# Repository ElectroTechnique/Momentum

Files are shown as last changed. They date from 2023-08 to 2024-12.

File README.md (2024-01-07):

# Momentum
Electrotechnique Momentum Synthesizer

3D Models - STL models of 3D printed components

Manual - User Manual including build guide

Momentum - Folder with source code, set-up for PlatformIO

SDCard - Folder with 'factory presets'. Copy the contents of the SDCard folder straight onto a formatted micro SD card

# Flashing firmware
Get the firmware hex file from [RELEASES](https://github.com/ElectroTechnique/Momentum/releases) on the right
See the User Manual sections on Flashing Firmware - use either TyUploader (recommended) or Teensy Loader.
TyUploader is in [TyTools Releases](https://github.com/Koromix/tytools/releases)
Teensy Loader is at [PJRC](https://www.pjrc.com/teensy/loader.html)

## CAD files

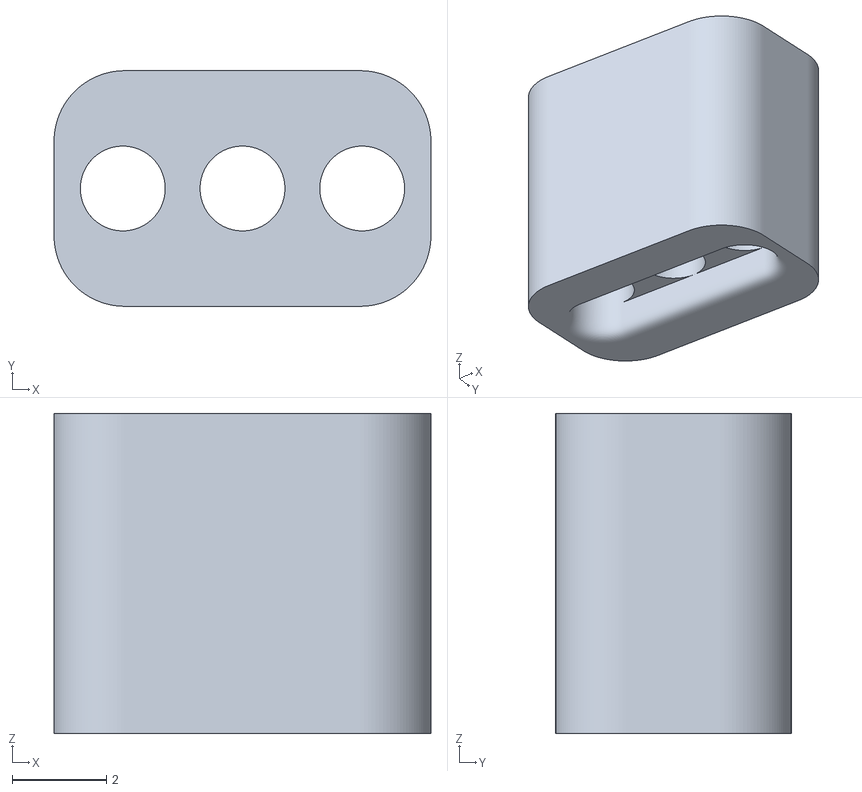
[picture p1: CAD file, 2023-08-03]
3D Models/3mm Bicolour LED Standoff.stl
8.00 x 5.00 x 6.80

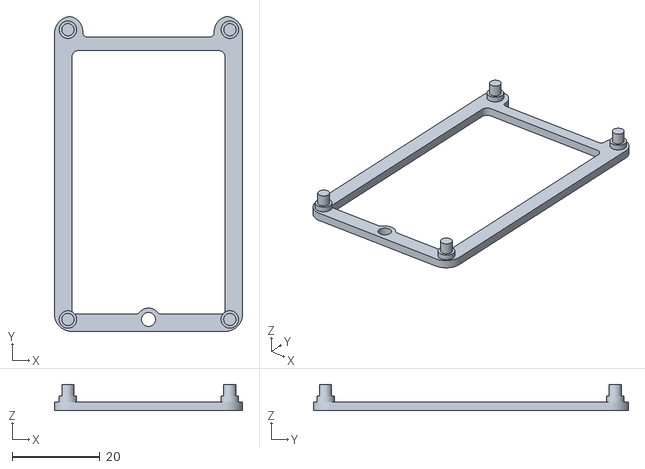
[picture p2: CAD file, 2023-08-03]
3D Models/240x320 TFT Standoff.stl
43.0 x 72.0 x 6.00

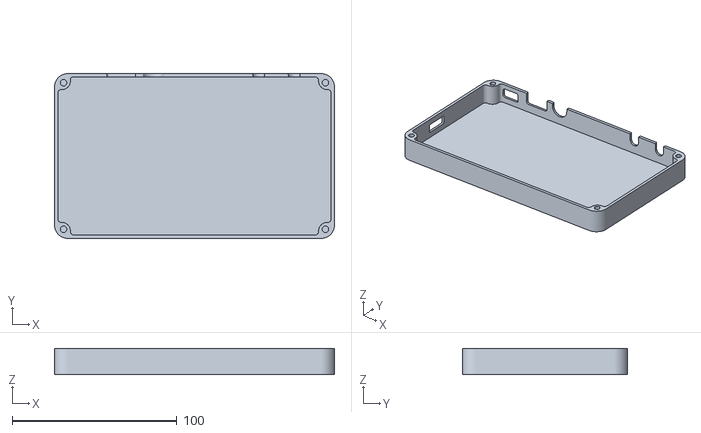
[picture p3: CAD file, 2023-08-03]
3D Models/Momentum Case USB C Brass Inserts.stl
170.0 x 100.0 x 16.0

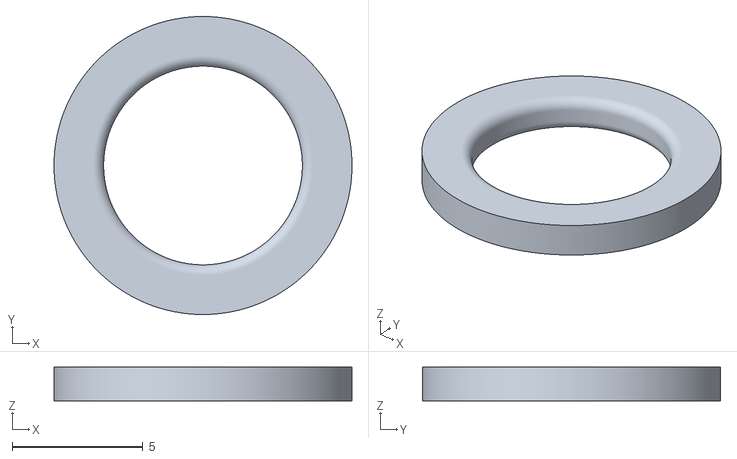
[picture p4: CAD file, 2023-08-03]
3D Models/Encoder Spacer.stl
11.4 x 11.4 x 1.30

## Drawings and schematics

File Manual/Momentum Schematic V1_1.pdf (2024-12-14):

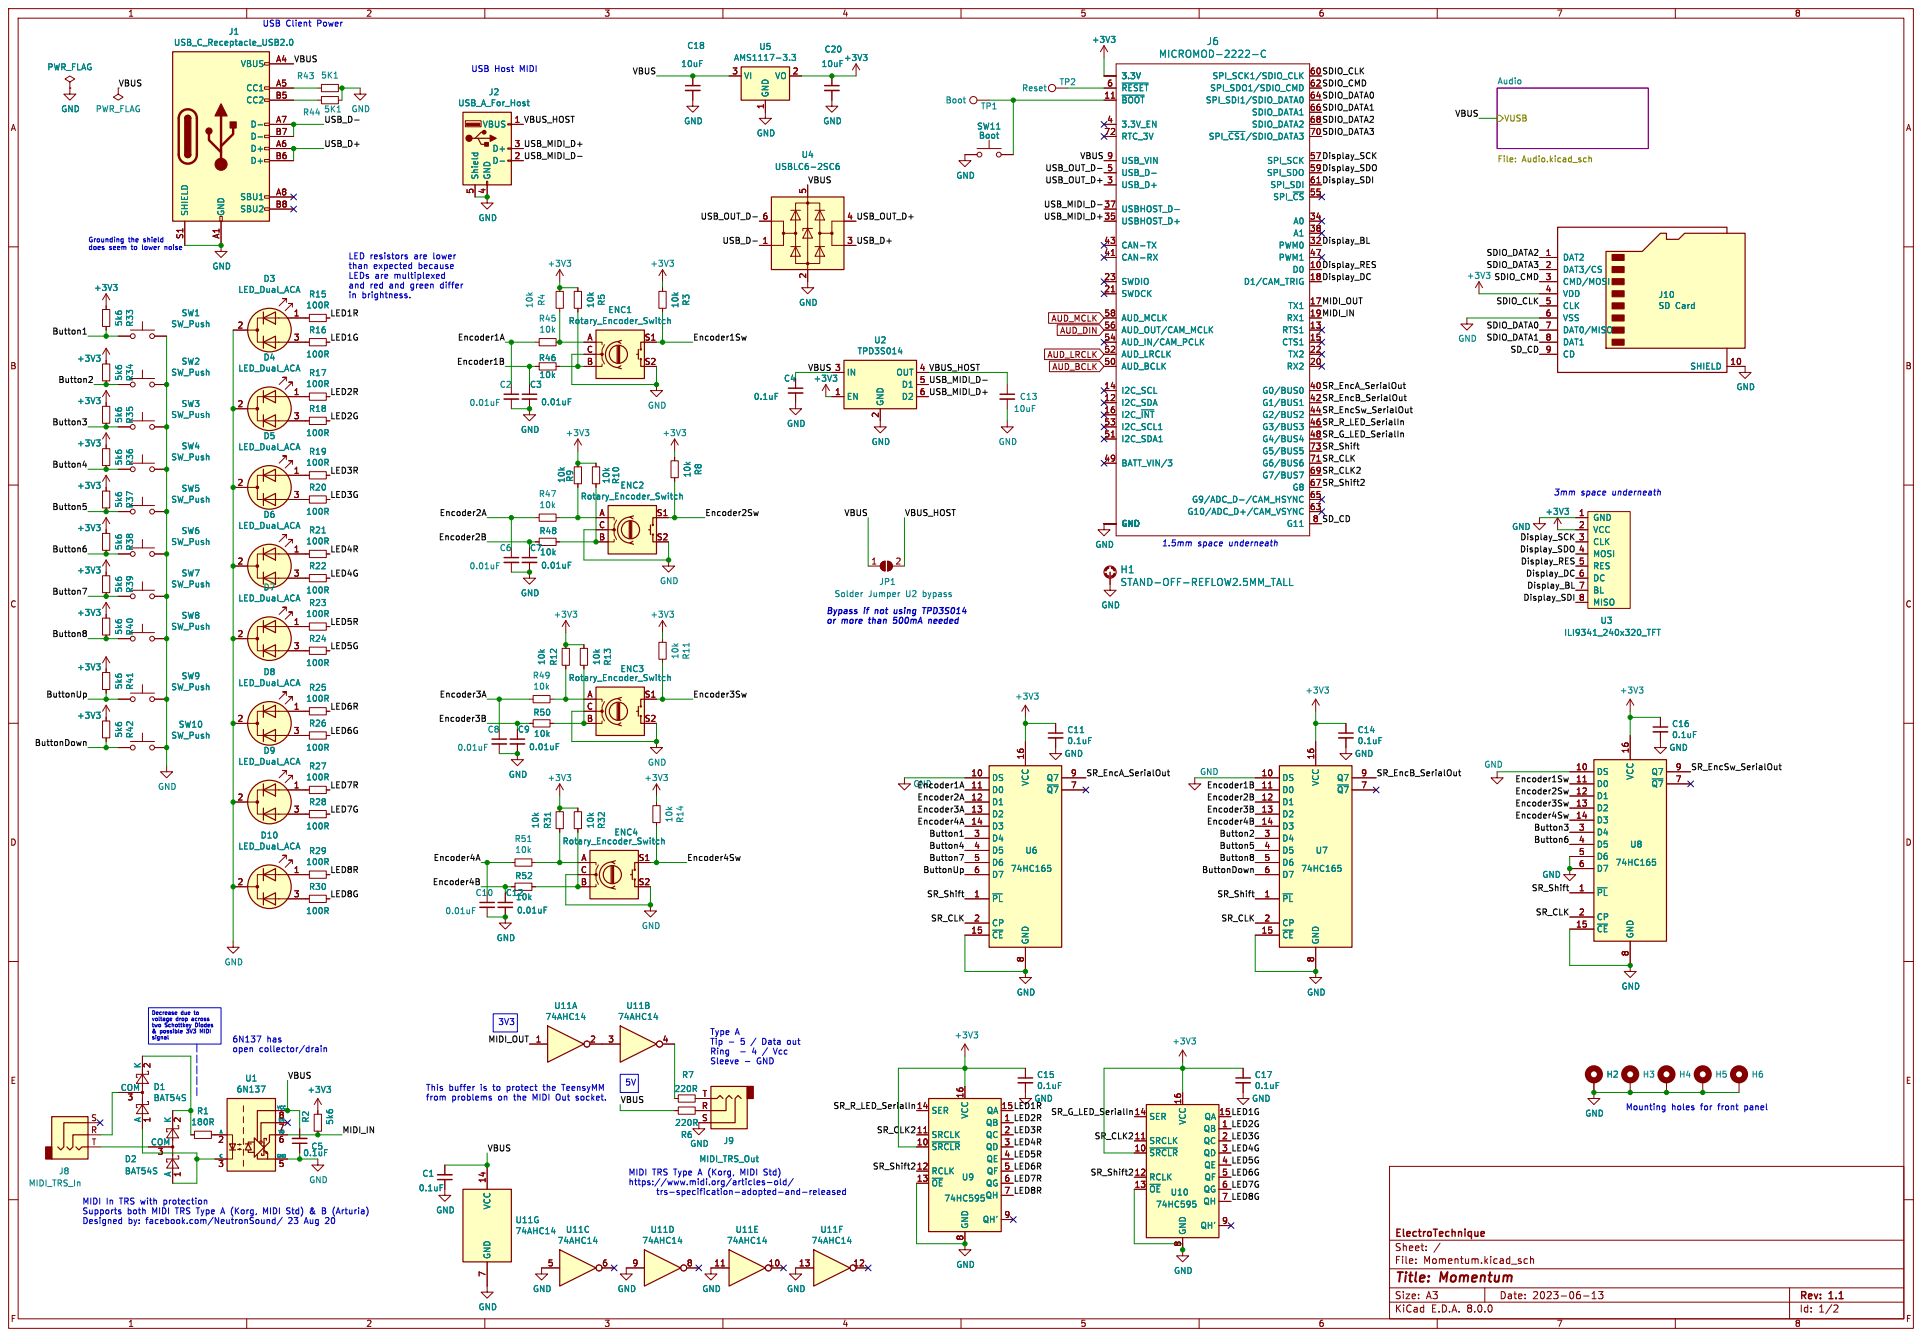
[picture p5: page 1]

does seem to lower noise

ILI9341_240x320_TFT GND 1 VCC 2 CLK 3 MOSI 4 RES 5 DC 6 BL 7 MISO 8 GND GND GND

Encoder1B MIDI TRS Type A (Korg, MIDI Std)

https://www.midi.org/articles-old/

trs-specification-adopted-and-released

Supports both MIDI TRS Type A (Korg, MIDI Std) & B (Arturia)

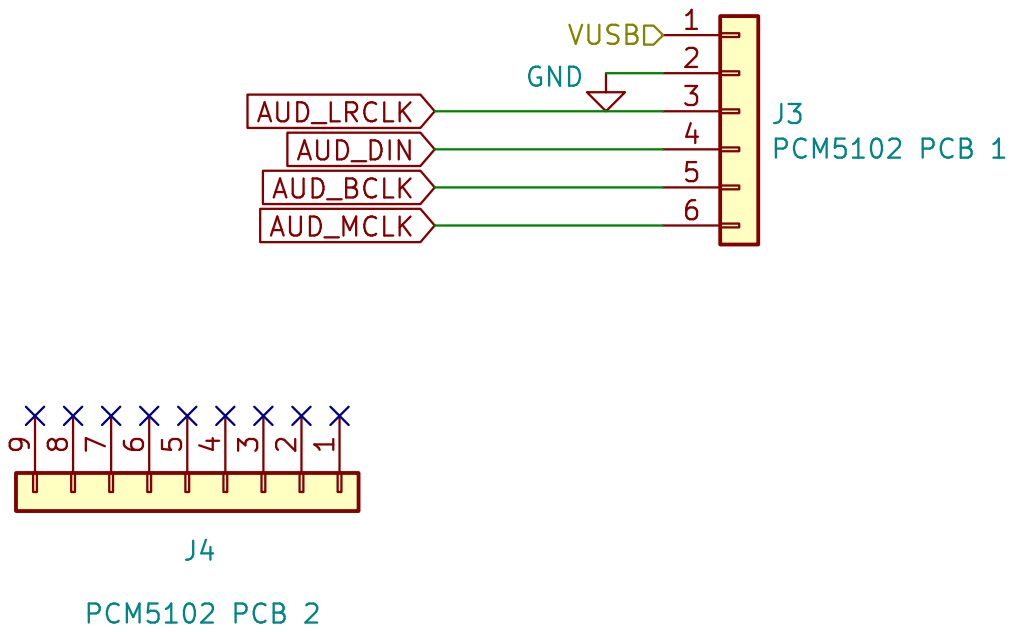
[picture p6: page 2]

File: Audio.kicad_sch Sheet: /Audio/
Id: 2/2 Title: PCM5102A PCB

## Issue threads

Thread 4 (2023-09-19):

Encoder acceleration is poor

ElectroTechnique, 2023-09-19:
Encoder acceleration needs looking at again. Currently it sends two or three callbacks when it detects that rotation pulses are more frequent.

ElectroTechnique, 2023-10-10:
Fixed in V1.02.

Closed 2023-10-10.

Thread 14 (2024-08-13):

Envelope.delay problem

rolfdegen, 2024-08-13:
Hallo TSynth. Nice projekt :)
But i have a problem with envelope.delay funktion in exp. envelope.  If I set envelope.delay to 6ms and play more notes, the envelope freezes. With 0ms delay, the envelope works without any problems. Envelope.delay from P. Stoffregen has no problems.

Thanks for your help :)

rolfdegen, 2024-08-16:
It looks as if the issue is that exp_count doesn't get set in noteOn(). If you trigger a new note exactly as the release phase finishes, so state == STATE_IDLE but an update() hasn't occurred to set exp_count to the delay value, it will have the stale value from the end of the decay phase, which is -2 32, so your delay suddenly becomes very long indeed.

rolfdegen, 2024-08-17:
Discussion in the Teensy Forum: https://forum.pjrc.com/index.php?threads/teensy-exponential-envelopes.75646/#post-348080

rolfdegen, 2024-08-17:
Result:
`
void AudioEffectEnvelope::noteOn(void)
{
  //__disable_irq();
  if(release_forced_count==0)
     state=STATE_IDLE;
  switch(state)
  {
    case STATE_IDLE:
    case STATE_IDLE_NEXT:
      count=delay_count;
      if(count>0)
      {
        state=STATE_DELAY;
        inc_hires=0;
      }
      else
      {
        state=STATE_ATTACK;
        count=attack_count;
      inc_hires = 0x40000000 / (int32_t)count;
      }
      exp_count=((uint32_t)(delay_count))*8; //!!!!FRE as per advise from h4yn0nnym0u5e teensy forum
      ysum=0;
      break;
    case STATE_DELAY:
    case STATE_HOLD:
    case STATE_ATTACK:
    case STATE_DECAY:
    case STATE_SUSTAIN:
    case STATE_SUSTAIN_FAST_CHANGE:
    case STATE_RELEASE:
      state=STATE_FORCED;
      count=release_forced_count;
      inc_hires=(-mult_hires)/(int32_t)count;
    case STATE_FORCED:
      break;
    default:
      state=STATE_RELEASE;
      break;
  }
  //__enable_irq();
}
`

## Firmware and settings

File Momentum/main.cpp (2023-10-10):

/*
   MIT License

  Copyright (c) 2023 ElectroTechnique

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
------------------------------------------------
            ELECTROTECHNIQUE MOMENTUM
  Teensy MicroMod based Synthesizer - 12 voices
------------------------------------------------

  Arduino IDE Tools Settings:
    Board: "Teensy MicroMod"
    USB Type: "Serial + MIDI + Audio"
    CPU Speed: "600MHz"
    Optimize: "Faster"

  This code is based on TSynth V2.32 firmware - ElectroTechnique 2021
  and includes code by:
    Dave Benn -  A few bits and original inspiration  https://www.notesandvolts.com/2019/01/teensy-synth-part-10-hardware.html
    Alexander Davis / Vince R. Pearson - Stereo ensemble chorus effect https://github.com/quarterturn/teensy3-ensemble-chorus
    Will Winder - Major refactoring and monophonic mode
    Vince R. Pearson - Exponential envelopes & glide
    Github members fab672000 & CDW2000 - General improvements to code
    Github/PJRC forum member luni64 - EncoderTool library modified https://github.com/luni64/EncoderTool
    PJRC forum member Mark Tillotson - Special thanks for band-limiting the waveforms in the Audio Library

    Any problems with code design and functionality are my own.

  Additional libraries:
    Janila Array, Adafruit_GFX, ArduinoJSON, TeensyTimerTool, TeensyThreads, RokkitHash (available in Arduino libraries manager)
*/
#define DEBUG 0

#include <Adafruit_GFX.h>
#include <ILI9341_t3n.h>
#include <vector>
#include "Audio.h" //Using local version to override Teensyduino version
#include <Wire.h>
#include <SPI.h>
#include <SD.h>
#include <MIDI.h>
#include <USBHost_t36.h>
#include <TeensyThreads.h>
#include <TeensyTimerTool.h>
using namespace TeensyTimerTool;
#include "MidiCC.h"
#include "SettingsService.h"
#include "AudioPatching.h"
#include "Constants.h"
#include "Parameters.h"

FLASHMEM void silence();
volatile boolean cardStatus = false;
volatile boolean sdCardInterrupt = false;
boolean usbHostPluggedIn = false;
elapsedMillis usb_host_wait_timer;
boolean MIDIClkSignal = false;

State state = State::MAIN;
boolean keyboardActive = false;

#include "PatchMgr.h"
#include "HWControls.h"
#include "EepromMgr.h"
#include "Detune.h"
#include "Keyboard.h"
#include "utils.h"
#include "Voice.h"
#include "VoiceGroup.h"

uint8_t majMin = MajMin::MAJOR;
uint8_t keyboardOct = 3;
uint8_t keyboardScale = 0;

// Initialize the audio configuration.
Global global{VOICEMIXERLEVEL};
std::vector<VoiceGroup *> groupvec;
uint8_t activeGroupIndex = 0;

#include "StringMapping.h"
#include "PerformanceMgr.h"

PeriodicTimer sequencer_timer(TCK); // TCK PIT GPT2
#include "SequenceMgr.h"
#include "EncoderMapping.h"

extern void sequencer();
extern void noteOnRoutine();

// USB HOST MIDI Class Compliant
USBHost myusb;
// MIDIDevice usbHostMIDI(myusb);
MIDIDevice_BigBuffer usbHostMIDI(myusb); // Try this if your MIDI Compliant controller has problems

// MIDI 5 Pin DIN - (TRS MIDI)
MIDI_CREATE_INSTANCE(HardwareSerial, Serial1, MIDI);

FLASHMEM void changeMIDIThruMode()
{
    MIDI.turnThruOn(MIDIThru);
}

FLASHMEM void myProgramChange(byte channel, byte program);
void myPitchBend(byte channel, int bend);
void myNoteOff(byte channel, byte note, byte velocity);
void myNoteOn(byte channel, byte note, byte velocity);
FLASHMEM void playNote(uint8_t note);
FLASHMEM void setCurrentPatchData();
FLASHMEM void recallPatch(uint8_t bank, long patchUID);
FLASHMEM void recallPerformance(uint8_t filename);
FLASHMEM void myControlChange(byte channel, byte control, byte value);
FLASHMEM void usbHostControlChange(byte channel, byte control, byte value);
FLASHMEM void myMIDIClock();
FLASHMEM void myMIDIClockContinue();
FLASHMEM void myMIDIClockStart();
FLASHMEM void myMIDIClockStop();
FLASHMEM void sequencerStart(boolean cont = false);
FLASHMEM void sequencerStop();
FLASHMEM void setSeqTimerPeriod(float bpm);

void midiCCOut(byte cc, byte value);
void encoderCallback(unsigned enc_idx, int value, int delta);
void encoderButtonCallback(unsigned button_idx, int state);
void buttonCallback(unsigned button_idx, int state);

#include "Display.h"
#include "Settings.h"

boolean firstPatchLoaded = false;

uint32_t previousMillis = millis(); // For MIDI Clk Sync
uint32_t timeNow = millis();        // For MIDI Clk Sync

uint8_t midiClkCount = 0;    // For MIDI Clk Sync
uint8_t midiClkArpCount = 0; // For MIDI Clk Sync with Arp
int voiceToReturn = -1;      // Initialise

uint8_t seq_last_step = 0;
uint8_t loopCount = 0;

FLASHMEM void setup()
{
    while (DEBUG == 1 && !Serial)
    {
    }
    AudioMemory(60);
    sequencer_timer.begin(sequencer, currentSequence.tempo_us / 2.0f, false);
    checkFirstRun();
    // Initialize the voice groups.
    uint8_t total = 0;
    while (total < global.maxVoices())
    {
        VoiceGroup *currentGroup = new VoiceGroup{global.SharedAudio[groupvec.size()]};

        for (uint8_t i = 0; total < global.maxVoices() && i < global.maxVoicesPerGroup(); i++)
        {
            Voice *v = new Voice(global.Oscillators[i], i);
            currentGroup->add(v);
            total++;
        }
        groupvec.push_back(currentGroup);
    }
    setUpSettings();
    SD.setMediaDetectPin(pinCD);
    cardStatus = SD.begin(BUILTIN_SDCARD);
    if (SD.mediaPresent()) // Card is detected by CD pin
    {
        // ++++ For older sd cards - keep trying
        if (!cardStatus)
            cardStatus = SD.begin(BUILTIN_SDCARD);
        if (!cardStatus)
            cardStatus = SD.begin(BUILTIN_SDCARD);
        if (!cardStatus)
            cardStatus = SD.begin(BUILTIN_SDCARD);
        //++++
    }
    if (cardStatus)
    {
        if (DEBUG)
            Serial.println(F("SD card is connected"));
        loadLastPatchUsed();
        currentSequenceIndex = getLastSequence();
        // Get patch numbers and names from SD card
        checkSDCardStructure();
        loadBankNames();
        loadPatchNamesFromBank(currentBankIndex);
        // If current patch is empty in this bank, go to previous bank with valid patch
        while (patches[0].patchUID == 0)
        {
            tempBankIndex = decTempBankIndex();
            loadPatchNamesFromBank(tempBankIndex);
            currentBankIndex = tempBankIndex;
            currentPatchIndex = 0;
        }
        recallPatch(currentBankIndex, patches[currentPatchIndex].patchUID);
    }
    else
    {
        setCurrentPatchData(); // Initialise to default
        if (DEBUG)
            Serial.println(F("SD card is not connected or unusable"));
    }

    // Read MIDI Channel from EEPROM
    midiChannel = getMIDIChannel();
    if (DEBUG)
        Serial.println(F("MIDI In Channel:") + String(midiChannel) + F(" (0 is Omni On)"));

    // USB Client MIDI
    usbMIDI.setHandleControlChange(myControlChange);
    usbMIDI.setHandleNoteOff(myNoteOff);
    usbMIDI.setHandleNoteOn(myNoteOn);
    usbMIDI.setHandlePitchChange(myPitchBend);
    usbMIDI.setHandleProgramChange(myProgramChange);
    usbMIDI.setHandleClock(myMIDIClock);
    usbMIDI.setHandleContinue(myMIDIClockContinue);
    usbMIDI.setHandleStart(myMIDIClockStart);
    usbMIDI.setHandleStop(myMIDIClockStop);
    if (DEBUG)
        Serial.println(F("USB Client MIDI Listening"));

    // MIDI 5 Pin DIN
    MIDI.begin();
    MIDI.setHandleNoteOn(myNoteOn);
    MIDI.setHandleNoteOff(myNoteOff);
    MIDI.setHandlePitchBend(myPitchBend);
    MIDI.setHandleControlChange(myControlChange);
    MIDI.setHandleProgramChange(myProgramChange);
    MIDI.setHandleClock(myMIDIClock);
    MIDI.setHandleContinue(myMIDIClockContinue);
    MIDI.setHandleStart(myMIDIClockStart);
    MIDI.setHandleStop(myMIDIClockStop);
    if (DEBUG)
        Serial.println(F("MIDI In DIN Listening"));

    // USB HOST MIDI Class Compliant
    myusb.begin();
    usbHostMIDI.setHandleControlChange(usbHostControlChange);
    usbHostMIDI.setHandleNoteOff(myNoteOff);
    usbHostMIDI.setHandleNoteOn(myNoteOn);
    usbHostMIDI.setHandlePitchChange(myPitchBend);
    usbHostMIDI.setHandleProgramChange(myProgramChange);
    usbHostMIDI.setHandleClock(myMIDIClock);
    usbHostMIDI.setHandleContinue(myMIDIClockContinue);
    usbHostMIDI.setHandleStart(myMIDIClockStart);
    usbHostMIDI.setHandleStop(myMIDIClockStop);
    if (DEBUG)
        Serial.println(F("USB HOST MIDI Class Compliant Listening"));

    // Read MIDI Out Channel from EEPROM
    midiOutCh = getMIDIOutCh();
    // Read MIDI Thru mode from EEPROM
    MIDIThru = getMidiThru();
    changeMIDIThruMode();
    // Read oscilloscope enable from EEPROM
    enableScope(getScopeEnable());
    // Read VU enable from EEPROM
    vuMeter = getVUEnable();
    // Read volume  from EEPROM
    currentVolume = getVolume();
    // Read global tuning from EEPROM
    tuningCents = getTuningCents();
    tuningCentsFrac = 1.0f + (tuningCents * CENTSFRAC);
    // Read arpeggiator settings from EEPROM
    arpDivision = getArpDivision();
    arpRange = getArpRange();
    arpStyle = getArpStyle();
    arpCycles = getArpCycles();
    if (arpCycles == ARP_HOLD)
        arpHold = true;
    arpBasis = getArpBasis();
    keyboardScale = getKeyboardScale();
    keyboardOct = getKeyboardBasis();
    sendCC = getSendCC();
    syncToMIDIClk = getSyncToMIDIClk();

    assignStrings();
    assignParametersForPerformanceEncoders();
    setupDisplay();
    setEncodersState(state);
    setupHardware(encoderCallback, encoderButtonCallback, buttonCallback);
}

// Specifically for Sequencer, bypassing recording note in and arp
FLASHMEM void noteOn(byte channel, byte note, byte velocity)
{
    // Check for out of range notes. Less than 20Hz isn't really audible
    if (note + groupvec[activeGroupIndex]->params().oscPitchA < 10 ||
        note + groupvec[activeGroupIndex]->params().oscPitchA > 127 ||
        note + groupvec[activeGroupIndex]->params().oscPitchB < 10 ||
        note + groupvec[activeGroupIndex]->params().oscPitchB > 127)
        return;
    groupvec[activeGroupIndex]->noteOn(note, velocity);
}

FLASHMEM void myNoteOn(byte channel, byte note, byte velocity)
{
    if (arpRunning)
    {
        // If it's in hold mode and you are not holding any notes down,
        // it continues to play the previous arpeggio. Once you press
        // a new note, it resets the arpeggio and starts a new one.
        // Also resets arpeggio from starting note.
        if (arpNotesHeld == 0)
        {
            resetNotes();
            // if (getNotesInArp() == 0)
            // {
            //     noteOn(midiChannel, note, velocity);
            //     setSeqTimerPeriod(currentSequence.bpm);
            //     sequencerStart();
            // }
        }
        if (arpNotesHeld < sizeof(arpNotes) - 1)
            arpNotesHeld++;
        else
            return;

        if (seqMidiSync && arpNotesHeld == 0)
            midiClkArpCount = 0;

        // find the right place to insert the note in the notes array
        if (arpStyle == PLAYORDER)
        {
            for (uint8_t i = 0; i < sizeof(arpNotes); i++)
            {
                if (arpNotes[i] == note)
                    return; // already in arpeggio
                else if (arpNotes[i] != '\0')
                    continue;
                else
                {
                    arpNotes[i] = note;
                    arpVels[i] = velocity;
                    return;
                }
            }
        }
        else
        {
            for (uint8_t i = 0; i < sizeof(arpNotes); i++)
            {
                if (arpNotes[i] == note)
                    return; // already in arpeggio
                else if (arpNotes[i] != '\0' && arpNotes[i] < note)
                    continue; // ignore the notes below it
                else
                {
                    // once we reach the first note in the arpeggio that's higher
                    // than the new one, move the rest of the arpeggio array over
                    // to the right
                    for (uint8_t j = sizeof(arpNotes) - 1; j > i; j--)
                    {
                        arpNotes[j] = arpNotes[j - 1];
                        arpVels[j] = arpVels[j - 1];
                    }

                    // and insert the note
                    arpNotes[i] = note;
                    arpVels[i] = velocity;
                    return;
                }
            }
        }
    }
    else
    {
        if (currentSequence.recording && currentSequence.running)
        {
            currentSequence.note_in = note;
            currentSequence.note_in_velocity = velocity;
        }
        else if (currentSequence.recording && !currentSequence.running && state == SEQUENCEEDIT)
        {
            currentSequence.Notes[currentSeqPosition] = note;
            currentSequence.Velocities[currentSeqPosition] = velocity;
            if (currentSeqPosition < currentSequence.length - 1)
                currentSeqPosition++;
            else
                currentSeqPosition = 0;

            currentSeqNote = note;
            if (currentSeqNote < 108)
                seqCurrentOctPos = nearbyint((currentSeqNote + 4) / 12) - 2;
        }
        noteOn(midiChannel, note, velocity);
    }
}

FLASHMEM void noteOff(byte channel, byte note, byte velocity)
{
    groupvec[activeGroupIndex]->noteOff(note);
}

FLASHMEM void myNoteOff(byte channel, byte note, byte velocity)
{
    if (arpRunning)
    {
        if (arpNotesHeld > 0)
            arpNotesHeld--;

        arpNotes[sizeof(arpNotes) - 1] = '\0';
        for (uint8_t i = 0; i < sizeof(arpNotes) - 1; i++)
        {
            // note released
            if (!arpHold && arpNotes[i] >= note)
            {
                // shift all notes in the array beyond or equal to the
                // note in question, thereby removing it and keeping
                // the array compact.
                arpNotes[i] = arpNotes[i + 1];
                arpVels[i] = arpVels[i + 1];
            }
        }
        // if (arpNotesHeld == 0 && getNotesInArp() == 0)
        //     sequencerStop();
    }
    noteOff(channel, note, velocity);
}

FLASHMEM void updatePatchnameAndIndex(String name, uint32_t index, uint32_t UID)
{
    groupvec[activeGroupIndex]->setPatchName(name);
    groupvec[activeGroupIndex]->setPatchIndex(index);
    groupvec[activeGroupIndex]->setUID(UID);
    setPatchNoAndNameForDisp(String(index), name);
}

FLASHMEM void myPitchBend(byte channel, int bend)
{
    groupvec[activeGroupIndex]->pitchBend(bend * currentPatch.PitchBend * DIV12xDIV8192);
}
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
void loop()
{
    // Improves USB digital audio - Checking USB client MIDI frequently causes drop-outs...
    if (loopCount++ > 15)
    {
        checkUSBHostStatus();
        // USB Host MIDI Class Compliant
        usbHostMIDI.read(midiChannel);
        // USB Client MIDI
        usbMIDI.read(midiChannel);
        // MIDI 5 Pin DIN
        MIDI.read(midiChannel);
        sdCardDetect();
        sequencerLEDs();
        // if (DEBUG)
        //     CPUMonitor();
        loopCount = 0;
    }
    encoders.read();
    buttons.read();
}

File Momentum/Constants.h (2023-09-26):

#pragma once

#include <stdint.h>
#include "Arduino.h"

#define PWMWAVEFORM WAVEFORM_TRIANGLE
#define BANKS_LIMIT 8          // 8 banks
#define PATCHES_LIMIT 128      // 128 patches per bank
#define PERFORMANCES_LIMIT 128 // 128 performances
#define SEQUENCES_LIMIT 128    // 128 sequences

// Used in myControlChange for 8 bit control of filter cutoff freq from front panel
#define filterfreq256 128
#define patchselect 129
#define savepatch 130
#define renamepatch 131
#define deletepatch 132
#define ampenvshape 134
#define filterenvshape 135
#define glideshape 136
#define pitchbendrange 137
#define pitchmodwheeldepth 138
#define namepatch 139
#define savebankselect 140
#define MIDIChIn 141
#define MIDIChOut 142
#define MIDIThruMode 143
#define PerfSelect 144
#define PerfEdit 145
#define cancel 146
#define settingoption 147
#define settingvalue 148
#define editbank 149
#define deletepatches 150
#define deletebank 151
#define renamebank 152
#define bankeditselect 153
#define choosecharacterPatch 154
#define choosecharacterBank 155
#define deleteCharacterPatch 156
#define deleteCharacterBank 157
#define savebank 158
#define chooseEncoderTL 159
#define chooseEncoderTR 160
#define chooseEncoderBL 161
#define chooseEncoderBR 162
#define chooseMIDIThruMode 163
#define chooseMIDIChIn 164
#define chooseMIDIChOut 165
#define deleteCharacterPerformance 166
#define choosecharacterPerformance 167
#define filtermodwheeldepth 168
#define choosePerfMIDIThruMode 169
#define choosePerfMIDIChIn 170
#define choosePerfMIDIChOut 171
#define SeqSelect 172
#define SeqEdit 173
#define deleteCharacterSequence 174
#define choosecharacterSequence 175
#define SeqTempo 176
#define SeqStartStop 177
#define goback 178
#define SeqNote 179
#define SeqPitch 180
#define SeqPosition 181
#define SeqLength 182
#define ArpStyle 183
#define ArpDivision 184
#define ArpRange 185
#define ArpCycle 186
#define ArpBasis 187
#define SeqDelete 188
#define PerfDelete 189
#define kbdOct 190
#define kbdScale 191
#define noencoder 255

const static char *SEQUENCE_FOLDER_NAME = "Sequences";
const static char *SEQUENCE_FOLDER_NAME_SLASH = "Sequences/";

const static char *BANKS_FILE_NAME = "Banknames";
const static char *BANK_FOLDER_NAMES[] = {"Bank1", "Bank2", "Bank3", "Bank4", "Bank5", "Bank6", "Bank7", "Bank8"};
const static char *BANK_FOLDER_NAMES_SLASH[] = {"Bank1/", "Bank2/", "Bank3/", "Bank4/", "Bank5/", "Bank6/", "Bank7/", "Bank8/"};
// Defaults to store on blank SD card
const static char *BANKS_FILE_CONTENTS = "{\"Bank1\": \"Strings\",\"Bank2\": \"Basses\", \"Bank3\": \"Keys\",\"Bank4\": \"FX\",\"Bank5\": \"User 1\",\"Bank6\": \"User 2\",\"Bank7\": \"User 3\",\"Bank8\": \"User 4\"}";

// Friendly bank names from Banknames file - defaults
static String bankNames[8] = {"Strings", "Basses", "Keys", "FX", "User 1", "User 2", "User 3", "User 4"};

const static char *PATCH_INDEX_FILE_NAME = "Patchindex";
// const static char *PATCH_INDEX_FILE_CONTENTS = "{\"1\":0,\"2\":0,\"3\":0,\"4\":0,\"5\":0,\"6\":0,\"7\":0,\"8\":0,\"9\":0,\"10\":0,\"11\":0,\"12\":0,\"13\":0,\"14\":0,\"15\":0,\"16\":0,\"17\":0,\"18\":0,\"19\":0,\"20\":0,\"21\":0,\"22\":0,\"23\":0,\"24\":0,\"25\":0,\"26\":0,\"27\":0,\"28\":0,\"29\":0,\"30\":0,\"31\":0,\"32\":0,\"33\":0,\"34\":0,\"35\":0,\"36\":0,\"37\":0,\"38\":0,\"39\":0,\"40\":0,\"41\":0,\"42\":0,\"43\":0,\"44\":0,\"45\":0,\"46\":0,\"47\":0,\"48\":0,\"49\":0,\"50\":0,\"51\":0,\"52\":0,\"53\":0,\"54\":0,\"55\":0,\"56\":0,\"57\":0,\"58\":0,\"59\":0,\"60\":0,\"61\":0,\"62\":0,\"63\":0,\"64\":0,\"65\":0,\"66\":0,\"67\":0,\"68\":0,\"69\":0,\"70\":0,\"71\":0,\"72\":0,\"73\":0,\"74\":0,\"75\":0,\"76\":0,\"77\":0,\"78\":0,\"79\":0,\"80\":0,\"81\":0,\"82\":0,\"83\":0,\"84\":0,\"85\":0,\"86\":0,\"87\":0,\"88\":0,\"89\":0,\"90\":0,\"91\":0,\"92\":0,\"93\":0,\"94\":0,\"95\":0,\"96\":0,\"97\":0,\"98\":0,\"99\":0,\"100\":0,\"101\":0,\"102\":0,\"103\":0,\"104\":0,\"105\":0,\"106\":0,\"107\":0,\"108\":0,\"109\":0,\"110\":0,\"111\":0,\"112\":0,\"113\":0,\"114\":0,\"115\":0,\"116\":0,\"117\":0,\"118\":0,\"119\":0,\"120\":0,\"121\":0,\"122\":0,\"123\":0,\"124\":0,\"125\":0,\"126\":0,\"127\":0,\"128\":0}";

const static char *PERFORMANCE_FOLDER_NAME = "Performances";
const static char *PERFORMANCE_FOLDER_NAME_SLASH = "Performances/";

const static char *EnvShapeStr[] = {"Lin", "Exp -8", "Exp -7", "Exp -6", "Exp -5", "Exp -4", "Exp -3", "Exp -2", "Exp -1", "Exp 0", "Exp +1", "Exp +2", "Exp +3", "Exp +4", "Exp +5", "Exp +6", "Exp +7", "Exp +8"};
const static char *GlideShapeStr[] = {"Lin", "Exp"};
const static char *MonophonicStr[] = {"Off", "Last", "First", "Highest", "Lowest"};

const static char *MIDIThruStr[] = {"Off", "Full", "Same Ch.", "Diff. Ch."};
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

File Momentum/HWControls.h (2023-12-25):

#include "ButtonTool/ButtonTool.h"
using namespace ButtonTool;
#include "EncoderTool/EncoderTool.h"
using namespace EncoderTool;

#include <avr/io.h>
#include <avr/interrupt.h>

// Encoder Shift Register numbering
#define ENC_TL 2
#define ENC_BL 3
#define ENC_TR 0
#define ENC_BR 1

// Because of the way the four encoders and ten buttons are arranged on three 74HC595 shift registers in parallel, these counts are not the same
constexpr unsigned encoderCount = 8; // There are four arranged over three Shift Registers on the last four positions, hence all eight positions must be shifted to reach them.
constexpr unsigned buttonCount = 12; // There are ten buttons, but arranged over three Shift Registers on the first four positions. The last four are skipped.

// These are Teensy numbering on https://learn.sparkfun.com/tutorials/micromod-teensy-processor-hookup-guide/all
constexpr unsigned srA = 40;   // output pin QH of shift register Enc pin A
constexpr unsigned srB = 41;   // output pin QH of shift register Enc pin B
constexpr unsigned srC = 42;   // output pin QH of shift register Button
constexpr unsigned pinLD = 45; // load pin for all shift registers
constexpr unsigned pinCLK = 6; // clock pin for all shift registers

constexpr unsigned latchPin = 26; // LEDs SR2
constexpr unsigned clockPin = 9;  // LEDs CLK2
constexpr unsigned dataPinG = 44; // Green LEDs data
constexpr unsigned dataPinR = 43; // Red LEDs data

constexpr unsigned pinCD = 27; // Card detect

uint8_t currentRLEDs = 0;
uint8_t currentGLEDs = 0;

EncPlex74165 encoders(encoderCount, pinLD, pinCLK, srB, srA, srC);
ButtonPlex74165 buttons(buttonCount, pinLD, pinCLK, srB, srA, srC);

void ledAnimation(long millis);

constexpr unsigned BACKLIGHT = 24; // A10/I2C_SCL1

typedef enum ledColour
{
  RED,
  GREEN,
  OFF,
} ledColour;

// typedef enum controlParameter
// {
//   control_noiseLevel,
//   control_pitchLfoRate,
//   control_pitchLfoWaveform,
//   control_pitchLfoAmount,
//   control_detune,
//   control_oscMix,
//   control_filterAttack,
//   control_filterDecay,
//   control_pwmAmountA,
//   control_waveformA,
//   control_pitchA,
//   control_pwmAmountB,
//   control_waveformB,
//   control_pitchB,
//   control_pwmRate,
//   control_pitchEnv,
//   control_attack,
//   control_decay,
//   control_sustain,
//   control_release,
//   control_filterLFOAmount,
//   control_FXMix,
//   control_FXAmount,
//   control_glide,
//   control_filterEnv,
//   control_filterRelease,
//   control_filterSustain,
//   control_filterType,
//   control_resonance,
//   control_cutoff,
//   control_filterLFORate,
//   control_filterLFOWaveform,
//   control_volume,
//   control_unison,
//   control_oscFX,
//   control_filterLFORetrig,
//   control_filterLFOMidiClkSync,
// } controlParameter;

const int16_t LED_TO_BIN[9] = {0, 1, 2, 4, 8, 16, 32, 64, 128}; // First value is dummy, LEDs are indexed 1-8

// Shift both red and green LEDs - FOR 595s IN PARALLEL
/*
Red: 2.1V 9mA
Green: 2.8V 1.5mA
*/
FLASHMEM void shiftOutParallel(uint8_t dataPinR, uint8_t dataPinG, uint8_t clockPin, uint8_t bitOrder, uint8_t valR, uint8_t valG)
{
  for (uint8_t i = 0; i < 8; i++)
  {
    if (bitOrder == LSBFIRST)
    {
      digitalWrite(dataPinR, valR & 1);
      valR >>= 1;
      digitalWrite(dataPinG, valG & 1);
      valG >>= 1;
    }
    else
    {
      digitalWrite(dataPinR, (valR & 128) != 0);
      valR <<= 1;
      digitalWrite(dataPinG, (valG & 128) != 0);
      valG <<= 1;
    }

    digitalWrite(clockPin, HIGH);
    digitalWrite(clockPin, LOW);
  }
}

// ledNo starts at 1
FLASHMEM void singleLED(ledColour color, int8_t ledNo)
{
  digitalWrite(latchPin, LOW);
  switch (color)
  {
  case RED:
    shiftOutParallel(dataPinR, dataPinG, clockPin, MSBFIRST, LED_TO_BIN[ledNo], 0);
    currentRLEDs = ledNo;
    currentGLEDs = 0;
    break;
  case GREEN:
    shiftOutParallel(dataPinR, dataPinG, clockPin, MSBFIRST, 0, LED_TO_BIN[ledNo]);
    currentGLEDs = ledNo;
    currentRLEDs = 0;
    break;
  case OFF:
    shiftOutParallel(dataPinR, dataPinG, clockPin, MSBFIRST, 0, 0);
    currentRLEDs = 0;
    currentGLEDs = 0;
    break;
  }
  digitalWrite(latchPin, HIGH);
}

FLASHMEM void lightRGLEDs(int8_t ledRNos, int8_t ledGNos)
{
  digitalWrite(latchPin, LOW);
  shiftOutParallel(dataPinR, dataPinG, clockPin, MSBFIRST, ledRNos, ledGNos);
  digitalWrite(latchPin, HIGH);
}

FLASHMEM void ledsOff()
{
  lightRGLEDs(0, 0);
  currentRLEDs = 0;
  currentGLEDs = 0;
}

// ledNo starts at 1
FLASHMEM void seqLED(ledColour color, int8_t ledNo)
{
  if (color == RED)
    lightRGLEDs(LED_TO_BIN[ledNo] + LED_TO_BIN[currentRLEDs], LED_TO_BIN[currentGLEDs]);
  else
    lightRGLEDs(LED_TO_BIN[currentRLEDs], LED_TO_BIN[ledNo] + LED_TO_BIN[currentGLEDs]);
}

FLASHMEM void flashLED(ledColour color, int8_t ledNo, int duration)
{
  if (color == RED)
    lightRGLEDs(LED_TO_BIN[ledNo] + LED_TO_BIN[currentRLEDs], LED_TO_BIN[currentGLEDs]);
  else
    lightRGLEDs(LED_TO_BIN[currentRLEDs], LED_TO_BIN[ledNo] + LED_TO_BIN[currentGLEDs]);
  delay(duration);
  lightRGLEDs(LED_TO_BIN[currentRLEDs], LED_TO_BIN[currentGLEDs]);
}

FLASHMEM void ledAnimation(long millis)
{
  lightRGLEDs(24, 0);
  delay(millis);
  lightRGLEDs(36, 0);
  delay(millis);
  lightRGLEDs(66, 0);
  delay(millis);
  lightRGLEDs(129, 0);
  delay(millis);
  lightRGLEDs(0, 0);
  delay(millis);
  lightRGLEDs(0, 129);
  delay(millis);
  lightRGLEDs(0, 66);
  delay(millis);
  lightRGLEDs(0, 36);
  delay(millis);
  lightRGLEDs(0, 24);
  delay(millis);
  lightRGLEDs(0, 0);
}

FLASHMEM void sdCardInteruptRoutine()
{
  detachInterrupt(pinCD);
  sdCardInterrupt = true;
}

FLASHMEM void setupHardware(EncoderTool::allCallback_t ec, EncoderTool::allBtnCallback_t ebc, ButtonTool::allBtnCallback_t bc)
{
  pinMode(latchPin, OUTPUT);
  pinMode(clockPin, OUTPUT);
  pinMode(dataPinG, OUTPUT);
  pinMode(dataPinR, OUTPUT);

  encoders.begin(CountMode::full);
  encoders.attachCallback(ec);
  encoders.attachBtnCallback(ebc);

  buttons.begin(bc);

  ledAnimation(50);

  pinMode(pinCD, INPUT_PULLUP);
  attachInterrupt(digitalPinToInterrupt(pinCD), sdCardInteruptRoutine, CHANGE);

  // Display backlight - Can be used to turn off or dim using PWM
  // Not used but you never know
  // pinMode(BACKLIGHT, OUTPUT);
}

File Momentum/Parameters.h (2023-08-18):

#pragma once
#include <stdint.h>
#include <MIDI.h>
#include <Constants.h>

// Globals used for Settings
extern byte midiChannel;
extern byte midiOutCh;
extern midi::Thru::Mode MIDIThru;
extern String patchName;
extern boolean encCW;
extern boolean vuMeter;
extern boolean sendCC;
extern boolean syncToMIDIClk;
extern int8_t tuningCents;
extern float tuningCentsFrac;

// Global patch modifiers
extern float lfoSyncFreq;
extern float lfoFilterTempoValue;
extern float lfoPitchTempoValue;

// Exponential envelopes
extern int8_t envTypeAmp;
extern int8_t envTypeFilt;
// Glide shape
extern int8_t glideShape;

extern uint8_t currentVolume;

extern int8_t charCursor;
extern int8_t nameCursor;

// extern uint8_t currentSettingsOption;
// extern uint8_t currentSettingsValue;

// *** Patch parameters to store the relative 7-bit values (Cutoff freq 8-bit) for patch store and modification by the encoders ***
// *** Initialised with a default patch to store when there are no patches on SD card ***
typedef struct PatchStruct
{
    uint32_t UID = 0;
    char PatchName[64] = "Init"; // INITPATCHNAME;
    uint8_t OscLevelA = 127;
    uint8_t OscLevelB = 127;
    uint8_t NoiseLevel = 63; // Centre off
    uint8_t Unison = 0;
    uint8_t OscFX = 0;
    uint8_t Detune = 20;      // 0.15%
    uint8_t KeyTracking = 63; // Half tracking, 0.5
    uint8_t Glide = 0;
    uint8_t PitchA = 0;     //-24
    uint8_t PitchB = 8;     //-12
    uint8_t WaveformA = 75; // Pulse
    uint8_t WaveformB = 75; // Pulse
    uint8_t PWMSourceA = 0;
    uint8_t PWMSourceB = 0;
    uint8_t PWMA_Amount = 63; // 0.50
    uint8_t PWMB_Amount = 63; // 0.50
    uint8_t PWMRateA = 10;    // 0.18Hz
    uint8_t PWMRateB = 10;    // 0.18Hz
    uint8_t PWA_Amount = 63;
    uint8_t PWB_Amount = 63;
    uint8_t FilterRes = 0;    // 0.71
    uint8_t FilterFreq = 255; // 12000Hz
    uint8_t FilterMixer = 0;
    uint8_t FilterEnv = 63;
    uint8_t PitchLFOAmt = 0;
    uint8_t PitchLFORate = 10;
    uint8_t PitchLFOWaveform = 0;
    uint8_t PitchLFORetrig = 0;
    uint8_t PitchLFOMidiClkSync = 0;
    uint8_t FilterLFORate = 10;
    uint8_t FilterLFORetrig = 0;
    uint8_t FilterLFOMidiClkSync = 0;
    uint8_t FilterLfoAmt = 0;
    uint8_t FilterLFOWaveform = 0;
    uint8_t FilterAttack = 0;
    uint8_t FilterDecay = 20;
    uint8_t FilterSustain = 80;
    uint8_t FilterRelease = 25;
    uint8_t Attack = 0;
    uint8_t Decay = 20;
    uint8_t Sustain = 80;
    uint8_t Release = 25;
    uint8_t EnsembleEffectAmt = 8;
    uint8_t EnsembleEffectMix = 31;
    uint8_t ReverbEffectTime = 8;
    uint8_t ReverbEffectMix = 0;
    uint8_t PitchEnv = 63; // Centre off
    uint8_t VelocitySensitivity = 0;
    uint8_t FilterVelocitySensitivity = 0;
    uint8_t ChordDetune = 0;
    uint8_t MonophonicMode = 0;
    uint8_t FilterEnvShape = 9; // Exp 0
    uint8_t AmpEnvShape = 9;    // Exp 0
    uint8_t GlideShape = 1;     // Exp
    uint8_t PitchBend = 7;
    uint8_t PitchModWheelDepth = 1;
    uint8_t FilterModWheelDepth = 0;
} PatchStruct;

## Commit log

2023-01-27 Patch saving, performance, defaults, key tracking and filter modulation.
2023-02-05 Add button held
2023-04-27 Prevent button press causing rotation changes
    [EncPlex74165.h]
2023-05-15 Two button press
2023-10-09 V1.02 - Improve encoder acceleration
2023-10-09 V1.02 - Improve encoder acceleration - Issue 4
2026-11-11 Reduce MIDI note latency and speed up display updates
    Ported from TSynth, plus Momentum specific changes:
    - Display thread: 1ms time slice (was 10ms, holding off MIDI handling),
    ~30ms frame pacing, and DMA screen updates so the ~18ms 320x240 SPI
    transfer no longer uses the CPU
    - Drain up to 16 pending messages per MIDI input each time they're read
    - Apply note on/off with the audio update blocked, so envelope triggers
    and pitch changes land in the same audio block (nest/ISR safe)
    - Note, pitch bend, MIDI clock and sequencer/arp step code run from RAM
    instead of flash; the sequencer runs in a timer ISR
    - Oscilloscope trace is drawn by the display thread instead of inside
    the audio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
2026-11-11 Rewrite ensemble effect (ported from TSynth)
    - LFO computed per sample; the delay time previously stepped every
    16-150 samples, causing zipper noise
    - 4-point Hermite delay interpolation instead of linear
    - Tap spacing restored to 60 degrees and right channel uses a 90 degree
    LFO shift, as originally intended
    - +6dB wet make-up gain (WET_DIVISOR) with saturation, so 100% mix
    keeps its level
    - Drops the 24KB LFO table
    Claude-Session: https://claude.ai/code/session_0193ESmtaemMRmCdtCXHMhSS
2026-11-11 Prevent oscillator mix clipping that caused aliasing (ported from TSynth)
    With Osc Mix centred both oscillators ran at full gain and their sum
    clipped the 16-bit waveform mixer. Osc 1 + Osc 2 + XOR are now scaled to
    a total gain of <= 1.0, with equal-power compensation after the filter.
    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
2026-11-11 Fix .progmem section type conflict between ArduinoJson and GFX font
    ArduinoJson's static 'factors' table and FreeMono9pt7b were both placed in
    .progmem with different section flags. Momentum doesn't pass flash strings
    to ArduinoJson, so its PROGMEM support isn't needed.
    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
2026-11-11 Replace mono Freeverb with stereo plate reverb after the ensemble
    - Plate reverb from hexefx_audiolib_i16 (Piotr Zapart, MIT), trimmed of
    pitch shift, shimmer and freeze; with those off its output is
    bit-identical to the original in host simulation
    - Routing is now voices -> ensemble -> reverb (stereo in/out, in series),
    with one reverb shared by both timbre slots after the ensemble outputs
    - Room size and mix keep their existing patch parameters; mix still goes
    up to 50:50. Reverb is bypassed at zero mix to save CPU
    - Tone settings fixed in Global (hidamp, lodamp, lowpass, hipass)
    - Replaces two Freeverbs that both ran continuously; frees ~50KB of DTCM.
    The reverb's ~120KB of dela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
2026-11-12 Fix CPUMonitor memory readout
    AudioMemoryUsageMax() is an integer block count; printing it with %f
    always showed 0. Also show current memory usage.
    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
2026-11-12 Improve oscilloscope: stable trigger, note-locked timebase, auto-scale
    - Schmitt trigger on rising zero crossings with sub-sample positioning,
    searched over two periods, so the trace stands still (host test: under
    0.3px frame-to-frame drift on clean signals, ~2px with heavy noise)
    - Timebase locked to the lowest held note's audible oscillator: shows two
    cycles, more for high notes, fewer for very low notes
    - Auto-scaled to the window (instant attack, slow release) instead of
    clipping anything above ~30% of full scale
    - Min/max per pixel column, or interpolated when under 2 samples per
    column, instead of taking every 4th sample
    - Taps the voices before the effects (after DC removal,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
2026-11-12 Fix lock-ups: thread-safe heap, larger display thread stack
    - malloc/free are now locked (newlib's __malloc_lock/__malloc_unlock were
    no-ops). The main loop and the display thread both build Strings, and
    a thread switch inside malloc could corrupt the heap and hang
    - Display thread gets an 8KB stack in DTCM instead of TeensyThreads'
    default 1KB on the heap, where an overflow silently corrupted the heap
    - CPUMonitor() also reports the most display thread stack used, and
    prints once a second (printing every loop could stall the main loop)
    - Prints the CrashReport, if any, once the Serial Monitor connects
    Claude-Session: https://c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
2026-11-13 Oscillator and filter improvements (ported from TSynth)
    Momentum's synth_waveform and filter_variable were identical to TSynth's,
    so these are TSynth's files as they are now:
    - Band-limited variable triangle (aliasing at 3.5kHz: width 0.5 -31 ->
    -65dB, width 0.95 -16 -> -53dB), exact under PWM and pitch changes
    - Band-limited pulse DC offset fixed (was -0.18 FS at every width)
    - Faster band-limited edges (~2x at high pitch); saw/square/pulse output
    bit-identical
    - Filter: 4x internal headroom and a soft limiter above 0.75 FS, so loud
    input at high resonance no longer overflows; input level lowered as
    resonance rises
    - Filter core is now a TPT (zero-delay feedback) SVF: accurate tuni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
2026-11-13 Voice stealing, display lock, patch recall debounce, Panic (from TSynth)
    Ported from TSynth and adapted to Momentum's UI:
    Voices and envelopes
    - Voice stealing prefers silent voices, then the oldest released voice,
    then the oldest held note (mono modes reuse the same voice)
    - A stolen voice changes level, pitch, filter velocity, key tracking and
    glide only after its 5ms forced release (new envelope wait state), so
    the old note's fade isn't heard at the new pitch/level
    - Noise level is included in the waveform mixer headroom scaling
    - Key tracking changes update held notes (Momentum's key tracking was
    otherwise already correct)
    - allNotesOff() resets the voice count and mono note his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
2026-11-14 Arp/sequencer: stop stray note-offs, seed Random, remove dead code
    - Releasing a key the arp is using no longer sends a voice note-off,
    which cut off an arp note of the same pitch (keys held before the arp
    started still get theirs)
    - The sequencer sends its note-off once, not again on every empty step,
    which cut off the same note played live
    - SequenceStruct note/transpose fields are initialised (a struct made on
    the stack for a missing sequence sent a note-off for a garbage note)
    - random() is seeded from the CPU cycle count at the first key press, so
    the Random arp differs after each power-up
    - Removed the first-note clock reset that could never run (arp keeps
    starting on the c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
2026-11-14 Arp starts on the key press; clamp tempo encoder value
    - On the internal clock a new arpeggio now plays its first note when the
    key is pressed and the step timer restarts from there, instead of
    waiting up to a whole division (e.g. 1/2s for 1/4 notes at 120bpm).
    A still-sounding note from the previous (latched) arpeggio is ended
    first. On MIDI clock the arp stays on the clock's grid
    - Note insertion moved into addArpNote() (same ordering as before)
    - Tempo is stored in the encoder's byte value clamped to 0-255 (the
    display uses the text, which was already correct above 255bpm;
    converting an out-of-range float to a byte is undefined)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
2026-11-14 CPU reductions, LFO smoothing, beat-locked clock sync (ported from TSynth V3.01)
    Ported from TSynth and adapted to Momentum:
    CPU
    - Silent voices cost nothing: once a voice's amp envelope has finished, its
    oscillators are suspended (so its filter and mixers skip too), resumed on
    the next note
    - Audio CPU overload guard (effect_cpuguard.h): if processing overruns for
    2 blocks it drops one voice instead of the synth hanging; reported on
    Serial
    - Oscillators generate whole blocks (variable triangle about half the
    instructions per sample; saw/square/pulse sample-identical)
    - Filter cutoff coefficients every 4 samples, interpolated; ensemble LFOs
    every 8 samples
    - AudioMixer4TS replac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
